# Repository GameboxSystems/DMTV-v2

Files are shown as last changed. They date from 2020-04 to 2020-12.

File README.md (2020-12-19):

# DMTV v2

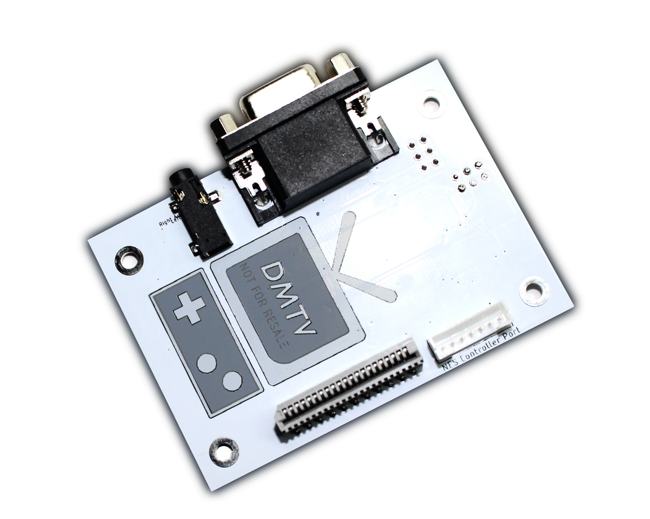
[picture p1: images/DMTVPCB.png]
DMTV v2 PCB


DMTV or "Dot Matrix Television" is an embedded solution to pair with a an original GameBoy console to provide 800x600 60Hz VGA out graphics, NES controller input, custom color palettes, and toggleable scanlines.

Unlike the original DMTV, this version no longer requires an atmega32u4 for controller handling. This feature is now baked directly into the source code using a simple shift register! This allows for a simplified board and lower BOM cost than before. Also includes all new color palettes.

To access scanlines and alternate color palettes, simply press Start + Select + A/B. The toggle is executed on the falling edge of the button press.

## Changes From v1

* No atmega32u4 for controller handling. This is now done by the FPGA via the nes_controller.v
* Addition of mosfet/diode arrays to simulate button presses for the Game Boy.
* Nes Port now built in!
* Mono audio included in ribbon cable. One wire required for pro sound mod.
* Greatly reduced BOM cost
* Color palettes don't hurt the eyes as much

## Getting Started

### Prerequisites

* Assembled DMTV v2 board (keep spi flash off board until after flashing)
* Windows/Linux computer (linux HIGHLY recommended)
* [APIO Icestorm](https://apiodoc.readthedocs.io/en/stable/) (iceCube2 will **NOT** synthesize source code correctly as it is not as optimized as APIO)
	* Either compile from source using APIO Icestorm or use provided precompiled binary
	* You can find install instructions on multiple platforms [here](https://apiodoc.readthedocs.io/en/stable/source/installation.html)
* Pomona SOIC-Clip Model 5252/buspirate v3.6 combo
	* This combo is for bypassing the expensive Lattice Diamond programmer cable
	* Pomona clip: https://www.digikey.com/product-detail/en/pomona-electronics/5252/501-2059-ND/745103
	* Buspirate v3.6: https://www.sparkfun.com/products/12942
* [flashrom](https://www.flashrom.org/Flashrom) 
* Not in the BOM, but a right angle NES port is required for controller support. You can find them [here](https://www.zedlabz.com/products/zedlabz-7-pin-90-degree-female-controller-connector-port-for-nintendo-nes-console-2-pack-black)

### Flashing FPGA SPI Flash Memory

Once a binary is obtained either through synthesis of source or using the precompiled binary, connect the buspirate to the SOIC clip as shown below.

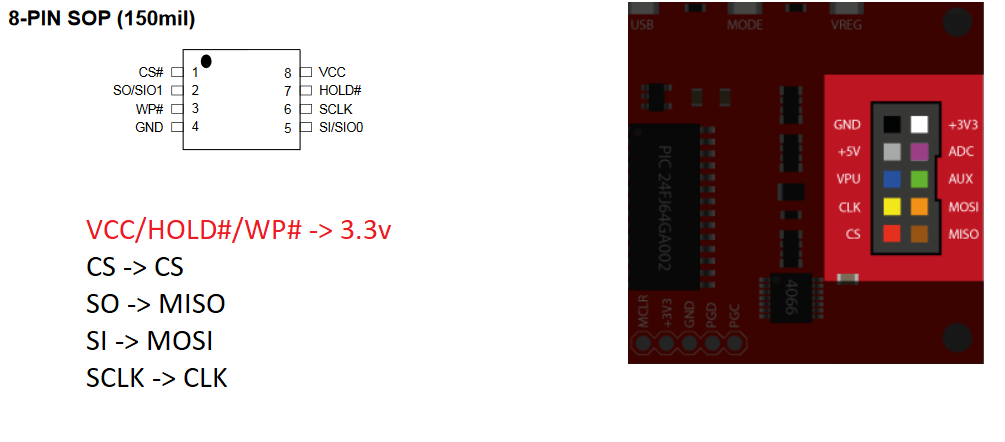
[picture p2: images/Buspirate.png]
Buspirate Connection


If using a binary output from APIO, you must resize the binary. Flashrom will not flash the spi memory until it is sized properly. Linux users, use the truncate command and windows users use your favorite hex editor to resize the binary.

For instructions on how to use buspirate with flashrom, use the official buspirate page on the flashrom website found here: https://flashrom.org/Bus_Pirate

After successful flash, solder to DMTV PCB.

### Notes on the HDL Code / Hardware

* Color palettes can be swapped for different color palettes if desired. The color code is RGB565 so any color space higher than that will need to be translated down. RGB888 can be added via hardware if desired as well, it will however reduce the amount of logic elements.
* If a different screen resolution is desired, swap out the current 40MHz oscillator for an oscialltor that matches timings consistant with that frequency. The code will need to be changed to reflect the profile as well. Use VGA profiles found here: http://tinyvga.com/vga-timing
* Resistor values go from greatest to smallest and are assigned such that the least significant assigned output pin for RGB goes to the highest ohm resistor downwards
	* i.e. R0 -> 8kohm, G -> 16kohm, B -> 8kohm, etc.

## Currently Known Issues

* Non currently found, please submit a pull request if you find one

## ToDo

* Add option to flash SPI flash via header instead
	* This was a challenge as there needs to be a way to sever the 3.3v power rail. If the SPI flash and the FPGA both have power then the SPI flash is not detected. The only work around known is to flash the SPI flash off the board and solder it on after flashing.
* SNES controller support

## Built With

* [APIO Icestorm](https://github.com/FPGAwars/apio)
* flashrom
* Eagle
* Sublime Text

## Versions

v1.0 - Initial release

## Contributing

Please feel free to issue a PR or edit code freely. Would love to have people contribute ideas!

## Authors

* **Postman** - *Head of engineering at Gamebox Systems*

## License

This project is licensed under the GPL-3.0 license, see attached license for info.

## Acknowledgments

* **ahhuhtal** - *DMTV v2 is based off of their gbvga project. Ahhuhtal, thank you for your wonderful description of how the first active pixel is after the falling edge of HSync. I was stuck on that for a long time.* - [ahhuhtal](https://github.com/ahhuhtal)

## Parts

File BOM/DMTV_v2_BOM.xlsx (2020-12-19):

Qty | Value | Package | Parts
17 | 0.1uF | C0603 | C1, C2, C3, C4, C5, C6, C7, C8, C9, C10, C11, C12, C13, C15, C16, C17, C18
1 | 100nF | C0603 | C14
2 | 22uF | CAPPM3216X180N | C28, C29
1 |  | SOD123 | D1
8 | 1N4148W-13-F | SOD3715X135N | D3, D4, D5, D6, D7, D8, D9, D10
1 | AMS1117-3.3 | SOT229P700X180-4N | IC2
1 | AMS1117-1.2 | SOT229P700X180-4N | IC3
1 | 181-015-213R561 | NORCOMP_181-015-213R561 | J1
1 |  | USB-MICROB | J2
1 | 2-1735446-7NES_PORT | NES_CONTROLLER_SOLDER_JACK | J3
1 | 35RASMT2BHNTRX | SWITCHCRAFT_35RASMT2BHNTRX | J4
4 | 2N7002DW-7-F | SOT65P210X100-6N | Q1, Q2, Q3, Q4
1 | 0R | R0603 | R1
1 | 22R | R0603 | R12
3 | 510R | R0603 | R14, R23, R31
3 | 1K | R0603 | R16, R24, R32
3 | 2K | R0603 | R17, R25, R33
3 | 4K | R0603 | R18, R26, R34
3 | 8K | R0603 | R19, R27, R35
1 | 2.2k | R0603 | R2
1 | 16K | R0603 | R28
2 | 82R | R0603 | R3, R4
3 | 10k | R0603 | R5, R11, R15
1 | MX25L1006EMI-10G | SOIC-8 | U$5
1 | 52808-21700520452145 | 520452145 | U$6
1 | ICE40HX1K-VQ100 | QFP50P1600X1600X120-100N | U1
2 | SN74LVC245APWR | SOP65P640X120-20N | U2, U3
1 | SI2301BDS | SOT95P240X111-3N | U5
1 | ASE-40.000MHZ-ET | SMD-3225_4P | Y1

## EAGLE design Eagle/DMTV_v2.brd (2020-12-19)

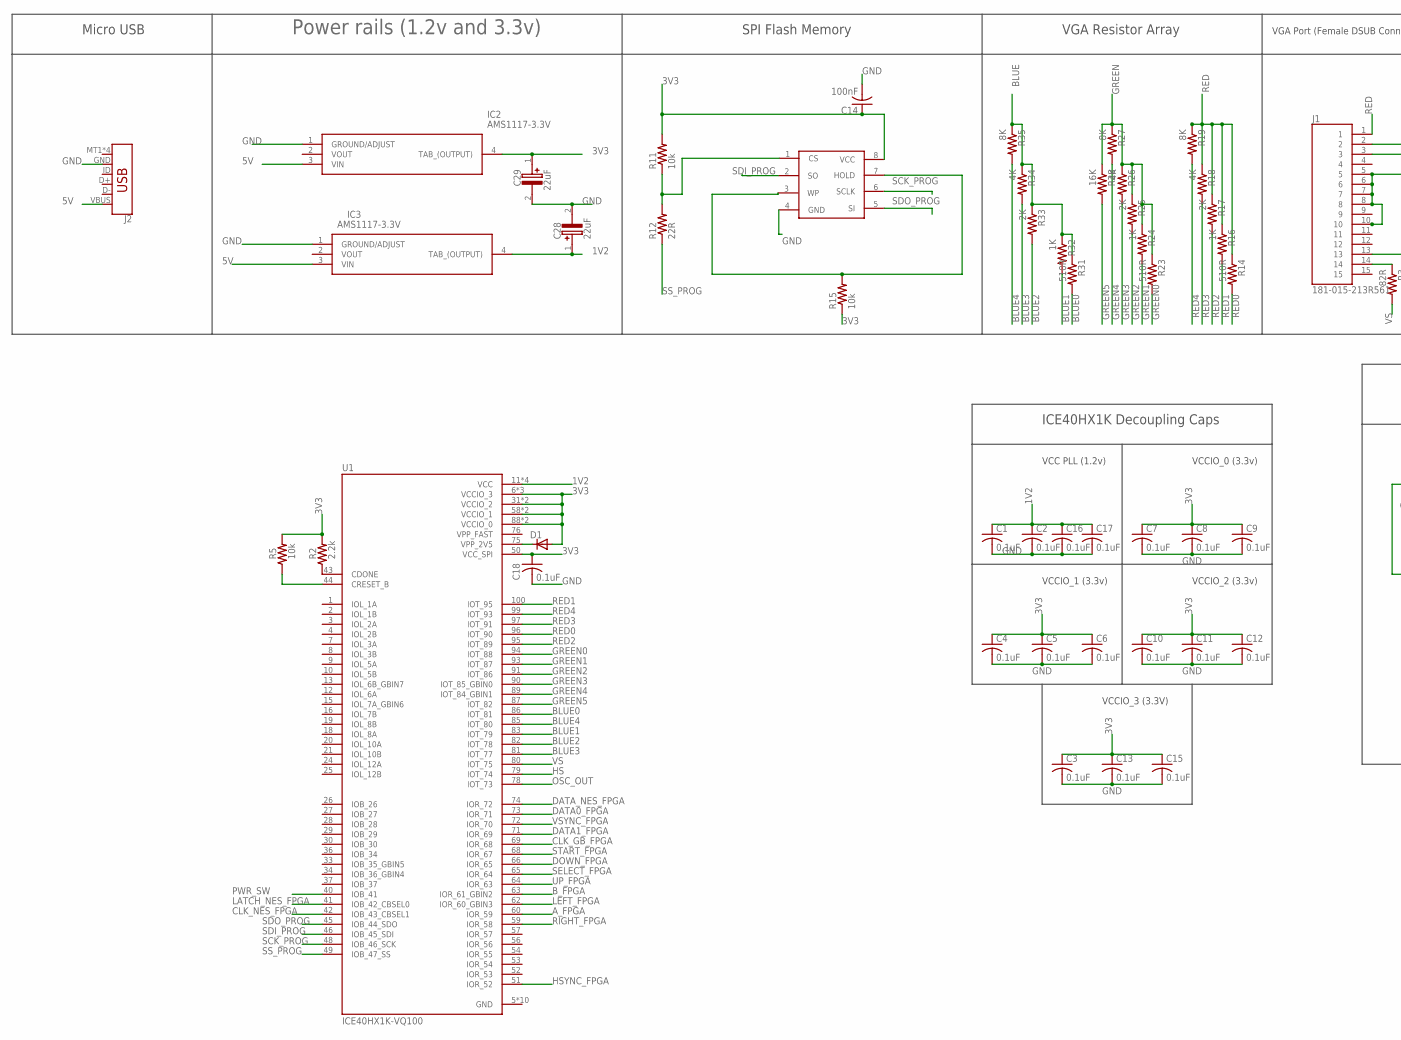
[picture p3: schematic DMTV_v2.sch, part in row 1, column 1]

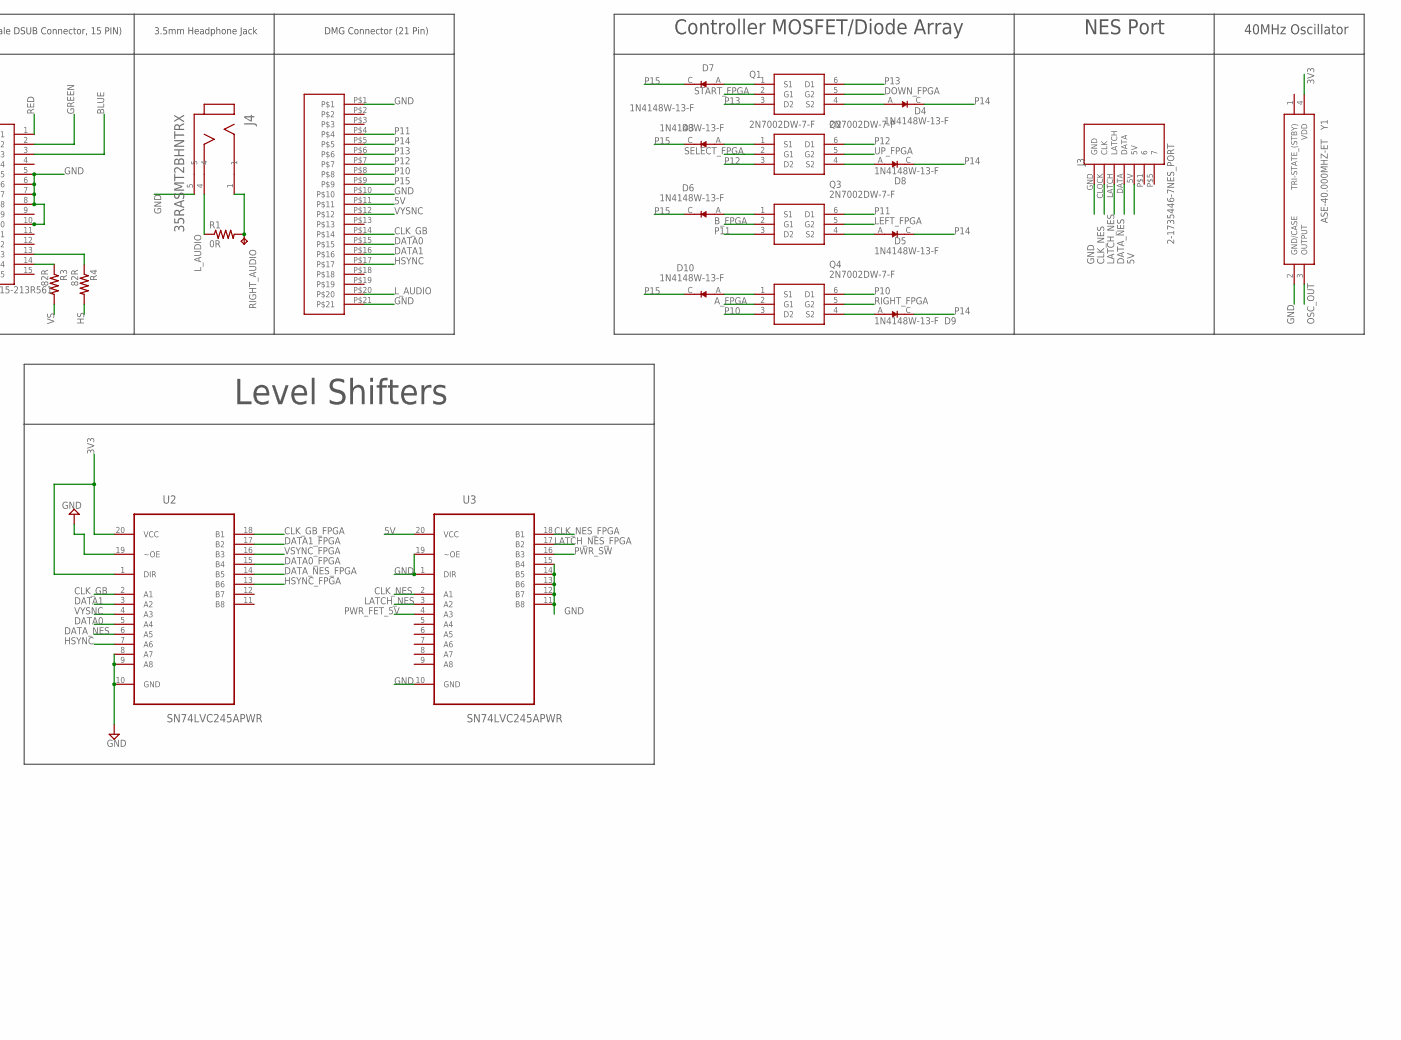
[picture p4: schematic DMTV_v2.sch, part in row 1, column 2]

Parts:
C1, C2, C3, C4, C5, C6, C7, C8, C9, C10, C11, C12, C13, C15, C16, C17, C18: 0.1uF; C0603
C14: 100nF; C0603
C28, C29: 22uF; CAPPM3216X180N
D1: D-SOD123; SOD123
D3, D4, D5, D6, D7, D8, D9, D10: 1N4148W-13-F; SOD3715X135N
IC2, IC3: AMS1117-3.3V; SOT229P700X180-4N
J1: 181-015-213R561; NORCOMP_181-015-213R561
J2: USB_MICRO-B_SMT; USB-MICROB
J3: 2-1735446-7NES_PORT; NES_CONTROLLER_SOLDER_JACK
J4: 35RASMT2BHNTRX; SWITCHCRAFT_35RASMT2BHNTRX
Q1, Q2, Q3, Q4: 2N7002DW-7-F; SOT65P210X100-6N
R1: 0R; R0603
R2: 2.2k; R0603
R3, R4: 82R; R0603
R5, R11, R15: 10k; R0603
R12: 22R; R0603
R14, R23, R31: 510R; R0603
R16, R24, R32: 1K; R0603
R17, R25, R33: 2K; R0603
R18, R26, R34: 4K; R0603
R19, R27, R35: 8K; R0603
R28: 16K; R0603
RIGHT_AUDIO: TPB2,54; B2,54
U1: ICE40HX1K-VQ100; QFP50P1600X1600X120-100N
U2, U3: SN74LVC245APWR; SOP65P640X120-20N
U$5: MX25L1006EMI-10G; SOIC-8
U$6: 52808-21700520452145; 0520452145
Y1: ASE-40.000MHZ-ET; ASE40000MHZET

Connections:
1V2: C1.1, C2.1, C16.1, C17.1, C28.1 (+), IC3.4 (TAB_(OUTPUT)), U1.11 (VCC), U1.35 (VCC), U1.61 (VCC), U1.77 (VCC)
3V3: C3.1, C4.1, C5.1, C6.1, C7.1, C8.1, C9.1, C10.1, C11.1, C12.1, C13.1, C14.1, C15.1, C18.1, C29.1 (+), D1.2 (A), IC2.4 (TAB_(OUTPUT)), R2.2, R5.2, R11.2, R15.1, U1.6 (VCCIO_3), U1.14 (VCCIO_3), U1.22 (VCCIO_3), U1.31 (VCCIO_2), U1.38 (VCCIO_2), U1.50 (VCC_SPI), U1.58 (VCCIO_1), U1.67 (VCCIO_1), U1.88 (VCCIO_0), U1.92 (VCCIO_0), U2.1 (DIR), U2.20 (VCC), U$5.8 (VCC), Y1.4 (VDD)
5V: IC2.3 (VIN), IC3.3 (VIN), J2.VBUS, J3.5V, U3.20 (VCC), U$6.P$11
A_FPGA: Q4.2 (G1), U1.60 (IOR_59)
BLUE: J1.3, R31.1, R32.1, R33.1, R34.1, R35.1
BLUE0: R31.2, U1.86 (IOT_81)
BLUE1: R32.2, U1.83 (IOT_79)
BLUE2: R33.2, U1.82 (IOT_78)
BLUE3: R34.2, U1.81 (IOT_77)
BLUE4: R35.2, U1.85 (IOT_80)
B_FPGA: Q3.2 (G1), U1.63 (IOR_61_GBIN2)
CLK_GB: U2.2 (A1), U$6.P$14
CLK_GB_FPGA: U1.69 (IOR_68), U2.18 (B1)
CLK_NES: J3.CLOCK (CLK), U3.2 (A1)
CLK_NES_FPGA: U1.42 (IOB_43_CBSEL1), U3.18 (B1)
DATA0: U2.5 (A4), U$6.P$15
DATA0_FPGA: U1.73 (IOR_71), U2.15 (B4)
DATA1: U2.3 (A2), U$6.P$16
DATA1_FPGA: U1.71 (IOR_69), U2.17 (B2)
DATA_NES: J3.DATA, U2.6 (A5)
DATA_NES_FPGA: U1.74 (IOR_72), U2.14 (B5)
DOWN_FPGA: Q1.5 (G2), U1.66 (IOR_65)
GND: C1.2, C2.2, C3.2, C4.2, C5.2, C6.2, C7.2, C8.2, C9.2, C10.2, C11.2, C12.2, C13.2, C14.2, C15.2, C16.2, C17.2, C18.2, C28.2 (-), C29.2 (-), IC2.1 (GROUND/ADJUST), IC3.1 (GROUND/ADJUST), J1.5, J1.6, J1.7, J1.8, J1.10, J2.GND, J3.GND, J4.5, U1.5 (GND), U1.17 (GND), U1.23 (GND), U1.32 (GND), U1.39 (GND), U1.47 (GND), U1.55 (GND), U1.70 (GND), U1.84 (GND), U1.98 (GND), U2.8 (A7), U2.9 (A8), U2.10 (GND), U2.19 (~OE), U3.1 (DIR), U3.10 (GND), U3.11 (B8), U3.12 (B7), U3.13 (B6), U3.14 (B5), U3.15 (B4), U3.19 (~OE), U$5.4 (GND), U$6.P$1, U$6.P$10, U$6.P$21, Y1.2 (GND/CASE)
GREEN: J1.2, R23.1, R24.1, R25.1, R26.1, R27.1, R28.1
GREEN0: R23.2, U1.94 (IOT_88)
GREEN1: R24.2, U1.93 (IOT_87)
GREEN2: R25.2, U1.91 (IOT_86)
GREEN3: R26.2, U1.90 (IOT_85_GBIN0)
GREEN4: R27.2, U1.89 (IOT_84_GBIN1)
GREEN5: R28.2, U1.87 (IOT_82)
HS: R4.2, U1.79 (IOT_74)
HSYNC: U2.7 (A6), U$6.P$17
HSYNC_FPGA: U1.51 (IOR_52), U2.13 (B6)
LATCH_NES: J3.LATCH, U3.3 (A2)
LATCH_NES_FPGA: U1.41 (IOB_42_CBSEL0), U3.17 (B2)
LEFT_FPGA: Q3.5 (G2), U1.62 (IOR_60_GBIN3)
L_AUDIO: J4.4, R1.1, U$6.P$20
unnamed: D1.1 (C), U1.75 (VPP_2V5)
unnamed: D7.A, Q1.1 (S1)
unnamed: J1.14, R3.1
unnamed: J1.13, R4.1
unnamed: J4.1, R1.2, RIGHT_AUDIO.TP
unnamed: R2.1, U1.43 (CDONE)
unnamed: R5.1, U1.44 (CRESET_B)
unnamed: R11.1, R12.2, U$5.1 (CS)
unnamed: D4.A, Q1.4 (S2)
unnamed: D3.A, Q2.1 (S1)
unnamed: D8.A, Q2.4 (S2)
unnamed: R15.2, U$5.3 (WP), U$5.7 (HOLD)
unnamed: D5.A, Q3.4 (S2)
unnamed: D9.A, Q4.4 (S2)
unnamed: D10.A, Q4.1 (S1)
unnamed: D6.A, Q3.1 (S1)
OSC_OUT: U1.78 (IOT_73), Y1.3 (OUTPUT)
P10: Q4.3 (D2), Q4.6 (D1), U$6.P$8
P11: Q3.3 (D2), Q3.6 (D1), U$6.P$4
P12: Q2.3 (D2), Q2.6 (D1), U$6.P$7
P13: Q1.3 (D2), Q1.6 (D1), U$6.P$6
P14: D4.C (K), D5.C (K), D8.C (K), D9.C (K), U$6.P$5
P15: D3.C (K), D6.C (K), D7.C (K), D10.C (K), U$6.P$9
PWR_FET_5V: U3.4 (A3)
PWR_SW: U1.40 (IOB_41), U3.16 (B3)
RED: J1.1, R14.1, R16.1, R17.1, R18.1, R19.1
RED0: R14.2, U1.96 (IOT_90)
RED1: R16.2, U1.100 (IOT_95)
RED2: R17.2, U1.95 (IOT_89)
RED3: R18.2, U1.97 (IOT_91)
RED4: R19.2, U1.99 (IOT_93)
RIGHT_FPGA: Q4.5 (G2), U1.59 (IOR_58)
SCK_PROG: U1.48 (IOB_46_SCK), U$5.6 (SCLK)
SDI_PROG: U1.46 (IOB_45_SDI), U$5.2 (SO)
SDO_PROG: U1.45 (IOB_44_SDO), U$5.5 (SI)
SELECT_FPGA: Q2.2 (G1), U1.65 (IOR_64)
SS_PROG: R12.1, U1.49 (IOB_47_SS)
START_FPGA: Q1.2 (G1), U1.68 (IOR_67)
UP_FPGA: Q2.5 (G2), U1.64 (IOR_63)
VPP_FAST: U1.76 (VPP_FAST)
VS: R3.2, U1.80 (IOT_75)
VSYNC_FPGA: U1.72 (IOR_70), U2.16 (B3)
VYSNC: U2.4 (A3), U$6.P$12

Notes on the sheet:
VCC PLL (1.2v)
VCCIO_0 (3.3v)
VCCIO_1 (3.3v)
VCCIO_2 (3.3v)
VCCIO_3 (3.3V)
ICE40HX1K Decoupling Caps
VGA Resistor Array
VGA Port (Female DSUB Connector, 15 PIN)
SPI Flash Memory
Power rails (1.2v and 3.3v)
Level Shifters
3.5mm Headphone Jack
DMG Connector (21 Pin)
Micro USB
Controller MOSFET/Diode Array
NES Port
40MHz Oscillator

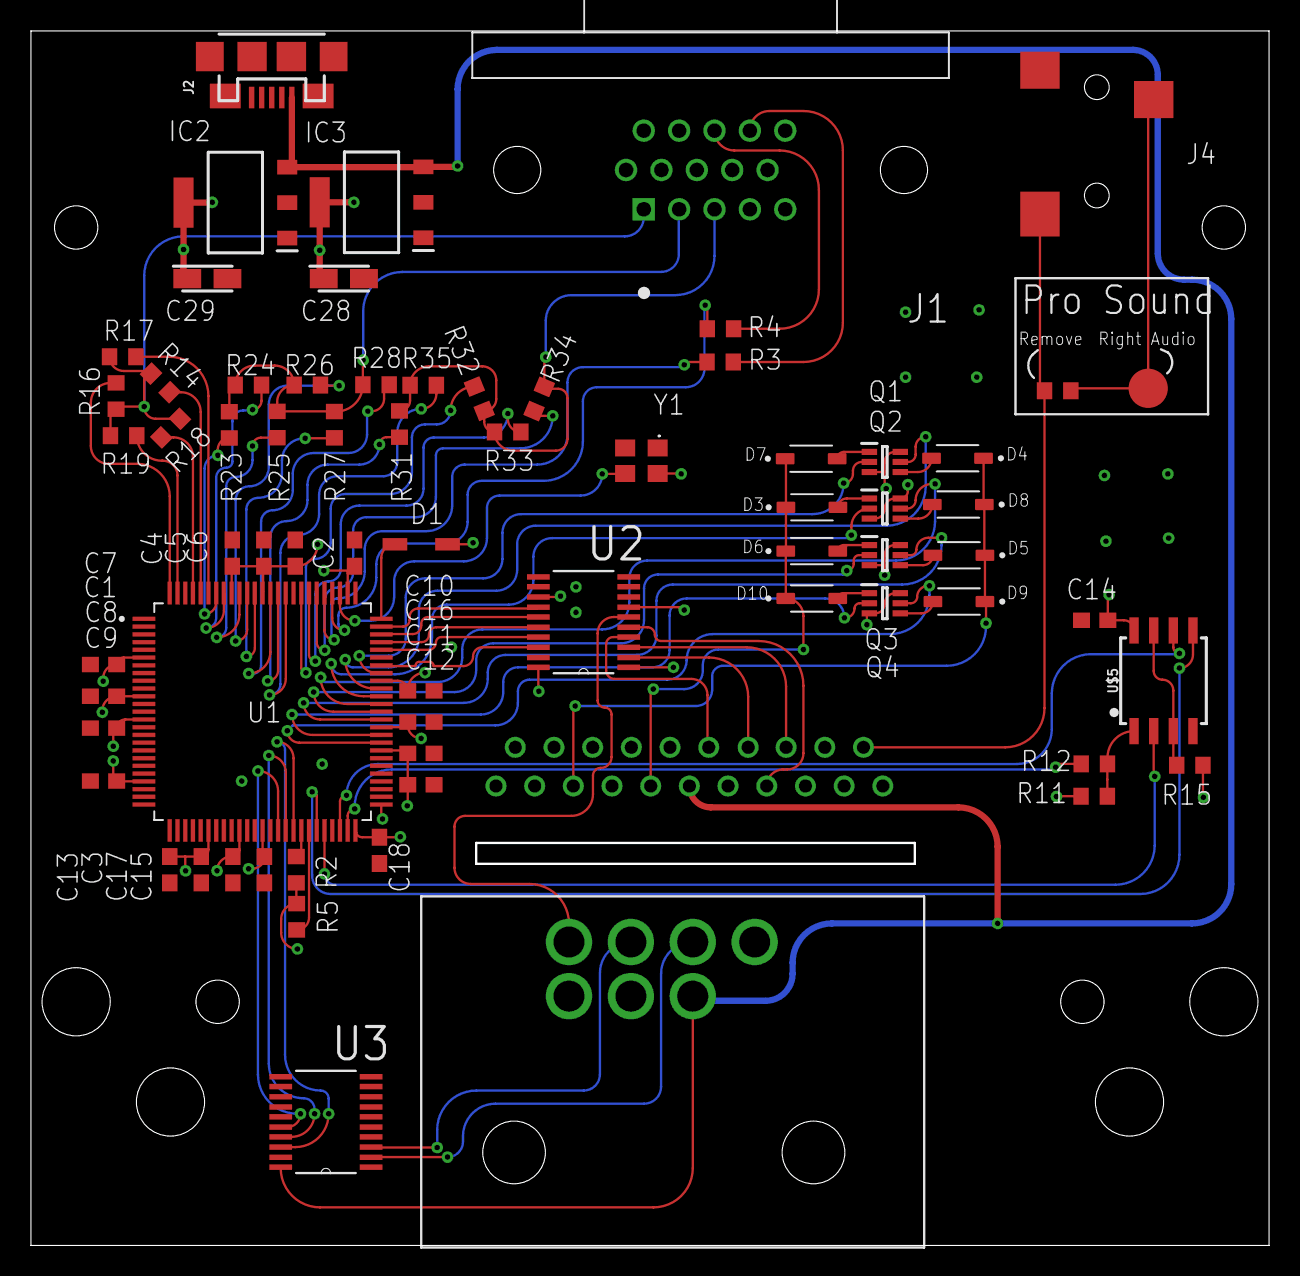
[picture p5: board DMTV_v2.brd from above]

Board: 4 copper layers, 80.0 x 78.5 mm, 71 parts (1 on the bottom side), 78 nets.

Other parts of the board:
U$1: DMTVPLS

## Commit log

2020-12-19 First Commit of DMTV v2
    [DMTV_v2.brd, DMTV_v2.sch, DMTV_v2_BOM.xlsx]
2020-12-19 removed arduino code
2020-12-19 Removed old verilog files and PCB layout and schematic files
    [DMTV_SD.brd, DMTV_SD.sch]
2020-12-19 Removed v1 BOM
    [DMTV_BOM.csv]

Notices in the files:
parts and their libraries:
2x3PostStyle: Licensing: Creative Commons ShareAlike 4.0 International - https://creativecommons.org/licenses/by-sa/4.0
